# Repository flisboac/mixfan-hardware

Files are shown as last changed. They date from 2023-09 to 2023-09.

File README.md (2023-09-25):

# mixfan-hardware

Hardware for the Mixfan, an USB-connected and powered 12V fan controller, that uses as much stock/cheap parts as possible. 

> TODO: PCB layout

Schematics: [docs/production/usb-fan-controller.pdf](docs/production/usb-fan-controller.pdf)

Schematics

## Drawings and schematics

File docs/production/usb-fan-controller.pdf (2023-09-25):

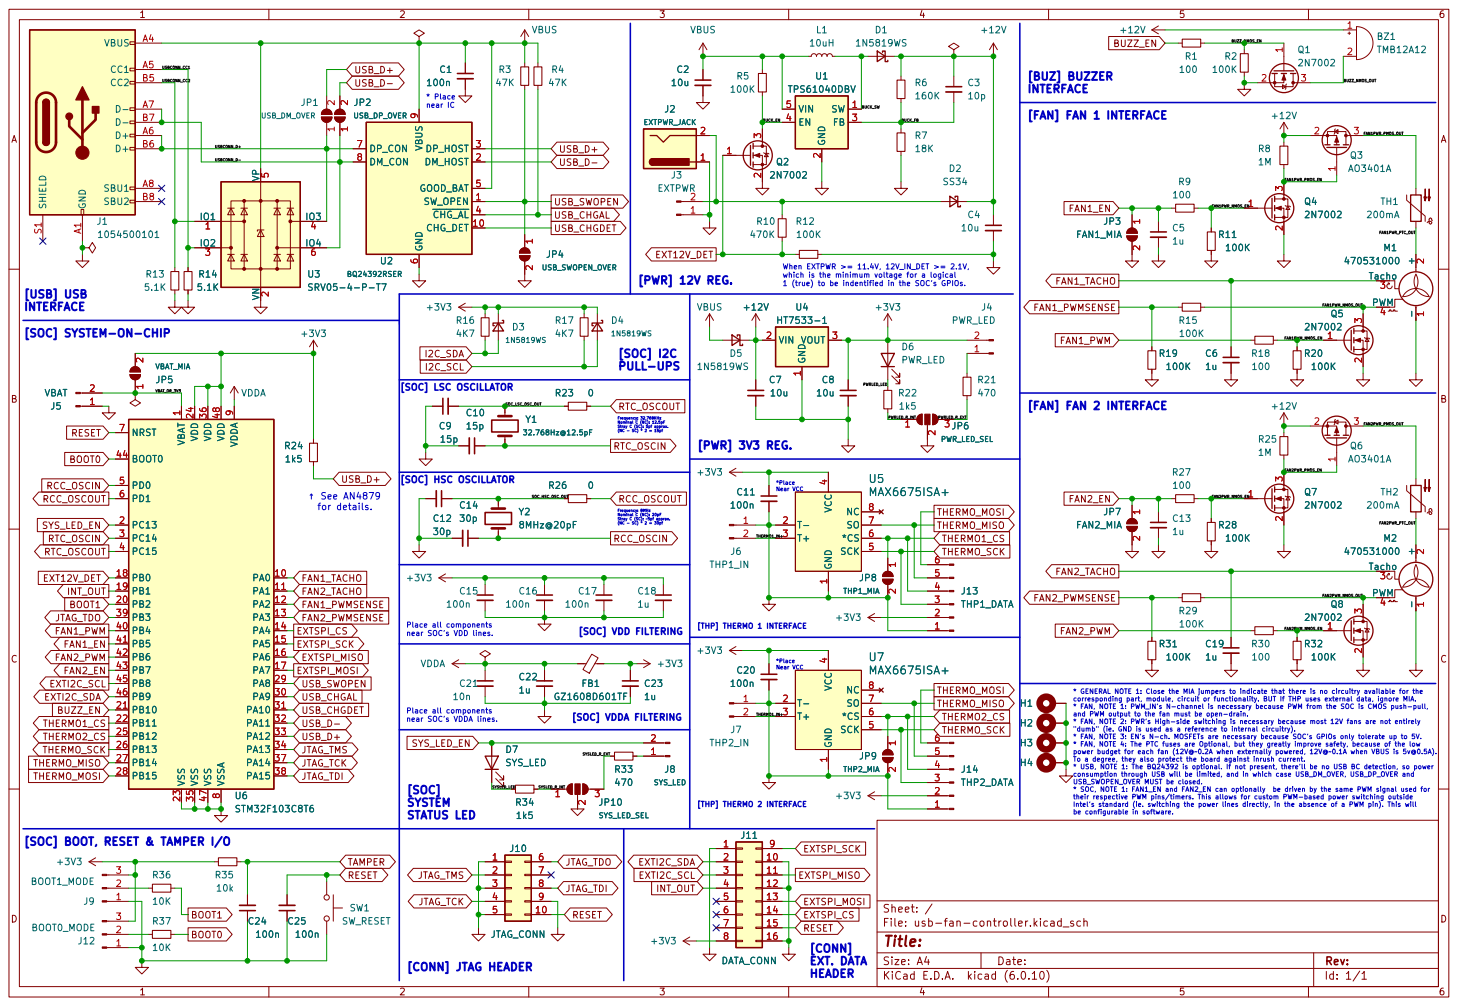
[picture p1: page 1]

When EXTPWR >= 11.4V, 12V_IN_DET >= 2.1V, which is the minimum voltage for a logical 1 (true) to be indentified in the SOC's GPIOs. [PWR] 3V3 REG.

[SOC] SYSTEM-ON-CHIP

1 PA0 10 PA1 11 PA2 12 PA3 13 PA4 14 PA5 15 PA6 16 PA7 17 PB0 18 PB1 19 PC13 2 PB2 20 PB10 21 PB11 22 VSS 23 VDD 24 PB12 25 PB13 26 PB14 27 PB15 28 PA8 29 PC14 3 PA9 30 PA10 31 PA11 32 PA12 33 PA13 34 VSS 35 VDD 36 PA14 37 PA15 38 PB3 39 PC15 4 PB4 40 PB5 41 PB6 42 PB7 43 BOOT0 44 PB8 45 PB9 46 VSS 47 VDD 48 PD0 5 PD1 6 NRST 7 VSSA

Frequency: 32,768KHz Nominal C (NC): 12.5pF Stray C (SC): 5pf approx. (NC - SC) * 2 = 15pf

Frequency: 8MHz Nominal C (NC): 20pF Stray C (SC): ~5pf approx. (NC - SC) * 2 = 30pf Place all components near SOC's VDDA lines.

* GENERAL NOTE 1: Close the MIA jumpers to indicate that there is no circuitry available for the
corresponding part, module, circuit or functionality. BUT If THP uses external data, ignore MIA. * FAN, NOTE 1: PWM_IN's N-channel is necessary because PWM from the SOC is CMOS push-pull, and PWM output to the fan must be open-drain. * FAN, NOTE 2: PWR's High-side switching is necessary because most 12V fans are not entirely

"dumb" (ie. GND is used as a reference to internal circuitry). * FAN, NOTE 3: EN's N-ch. MOSFETs are necessary because SOC's GPIOs only tolerate up to 5V. * FAN, NOTE 4: The PTC fuses are Optional, but they greatly improve safety, because of the low

power budget for each fan (12V@~0.2A when externally powered, 12V@~0.1A when VBUS is 5v@0.5A). To a degree, they also protect the board against inrush current. * USB, NOTE 1: The BQ24392 is optional. If not present, there'll be no USB BC detection, so power consumption through USB will be limited, and in which case USB_DM_OVER, USB_DP_OVER and USB_SWOPEN_OVER MUST be closed. * SOC, NOTE 1: FAN1_EN and FAN2_EN can optionally be driven by the same PWM signal used for

their respective PWM pins/timers. This allows for custom PWM-based power switching outside
Intel's standard (ie. switching the power lines directly, in the absence of a PWM pin). This will be configurable in software.

[SOC] BOOT, RESET & TAMPER I/O

File: usb-fan-controller.kicad_sch Sheet: / R35

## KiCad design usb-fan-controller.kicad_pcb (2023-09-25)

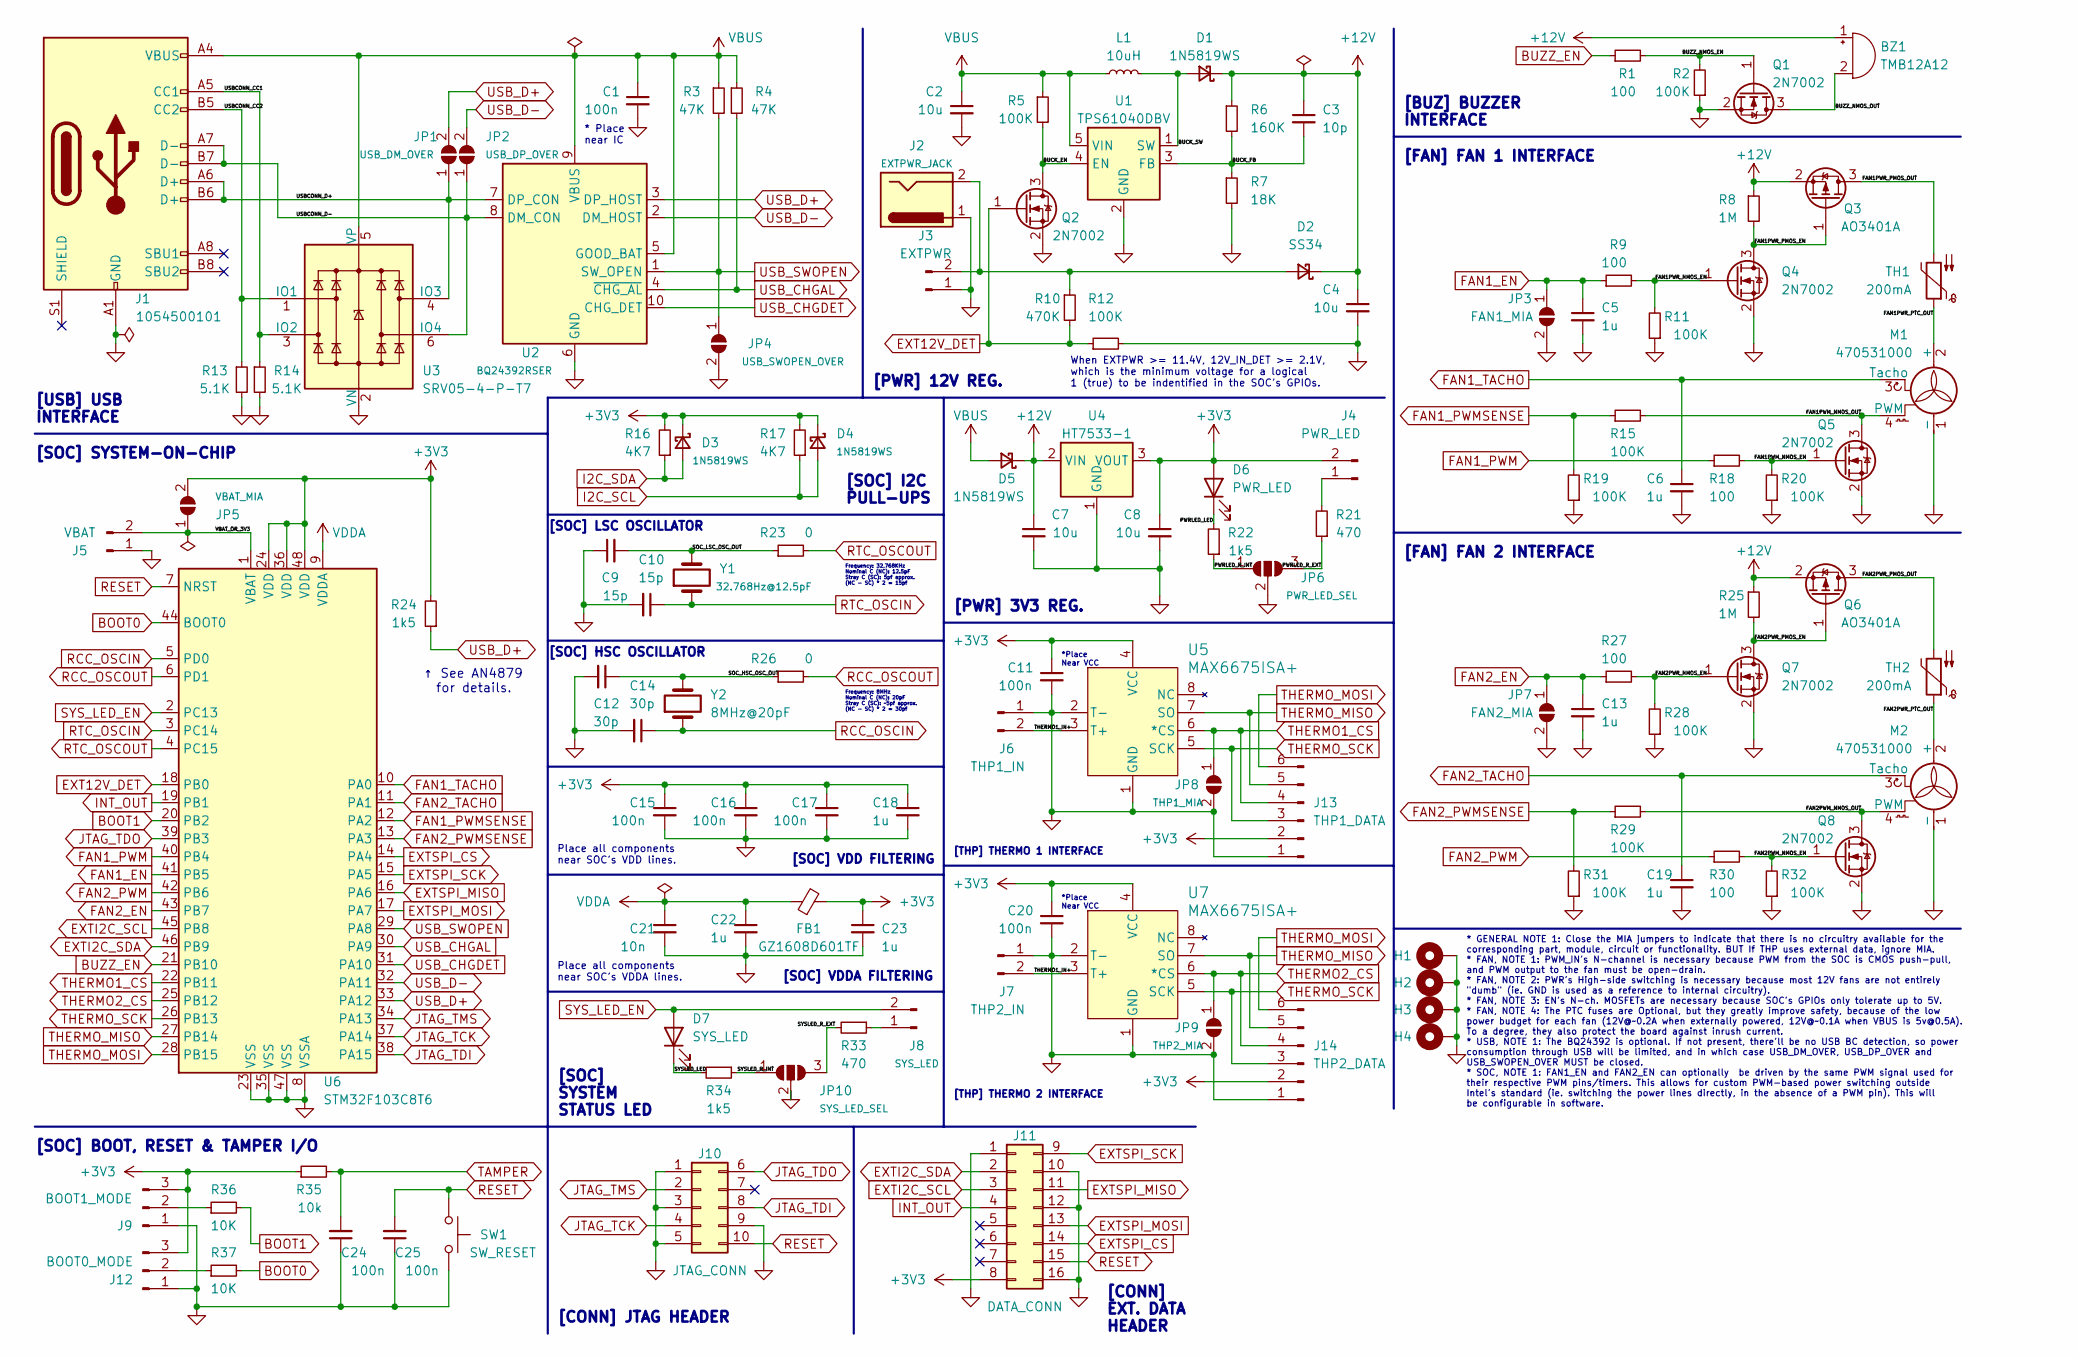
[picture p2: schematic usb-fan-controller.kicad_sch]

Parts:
BZ1: TMB12A12; Buzzer_12x9.5RM7.6; JLCPCB Part C96079
C1, C11, C15, C16, C17, C20, C24, C25: 100n; C_0402_1005Metric_Pad0.74x0.62mm_HandSolder
C2, C4, C7, C8: 10u; C_0603_1608Metric; JLCPCB Part C96446
C3: 10p; C_0402_1005Metric; JLCPCB Part C32949
C5, C6, C13, C18, C19, C22, C23: 1u; C_0402_1005Metric; JLCPCB Part C52923
C9, C10: 15p; C_0402_1005Metric_Pad0.74x0.62mm_HandSolder; JLCPCB Part C32949
C12, C14: 30p; C_0603_1608Metric; JLCPCB Part C1658
C21: 10n; C_0402_1005Metric_Pad0.74x0.62mm_HandSolder; JLCPCB Part C15195
D1, D3, D4, D5: 1N5819WS; D_SOD-323
D2: SS34; D_SMA; JLCPCB Part C8678
D6: PWR_LED; D_0603_1608Metric; JLCPCB Part C2286
D7: SYS_LED; D_0603_1608Metric; JLCPCB Part C2286
FB1: GZ1608D601TF; L_0603_1608Metric
H1, H2, H3, H4: MountingHole_Pad; MountingHole_2.2mm_M2_Pad_Via
J1: 1054500101; USB_C_Receptacle_Molex_105450-0101; JLCPCB Part C134092
J2: EXTPWR_JACK; BarrelJack_CLIFF_FC681465S_SMT_Horizontal
J3: EXTPWR; TerminalBlock_bornier-2_P5.08mm; JLCPCB Part C8465
J4: PWR_LED; LED_D3.0mm; JLCPCB Part C8465
J5: VBAT; JST_PH_B2B-PH-K_1x02_P2.00mm_Vertical; JLCPCB Part C8465
J6: THP1_IN; TerminalBlock_bornier-2_P5.08mm; JLCPCB Part C8465
J7: THP2_IN; TerminalBlock_bornier-2_P5.08mm; JLCPCB Part C8465
J8: SYS_LED; LED_D3.0mm; JLCPCB Part C8465
J9: BOOT1_MODE; PinHeader_1x03_P2.54mm_Vertical
J10: JTAG_CONN; PinHeader_2x05_P2.54mm_Horizontal
J11: DATA_CONN; PinHeader_2x08_P2.54mm_Vertical
J12: BOOT0_MODE; PinHeader_1x03_P2.54mm_Vertical
J13: THP1_DATA
J14: THP2_DATA; PinHeader_1x06_P2.54mm_Horizontal
JP1: USB_DM_OVER; SolderJumper-2_P1.3mm_Open_RoundedPad1.0x1.5mm
JP2: USB_DP_OVER; SolderJumper-2_P1.3mm_Open_RoundedPad1.0x1.5mm
JP3: FAN1_MIA; SolderJumper-2_P1.3mm_Open_RoundedPad1.0x1.5mm
JP4: USB_SWOPEN_OVER; SolderJumper-2_P1.3mm_Open_RoundedPad1.0x1.5mm
JP5: VBAT_MIA; SolderJumper-2_P1.3mm_Open_RoundedPad1.0x1.5mm
JP6: PWR_LED_SEL; SolderJumper-3_P1.3mm_Open_RoundedPad1.0x1.5mm
JP7: FAN2_MIA; SolderJumper-2_P1.3mm_Open_RoundedPad1.0x1.5mm
JP8: THP1_MIA; SolderJumper-2_P1.3mm_Open_RoundedPad1.0x1.5mm
JP9: THP2_MIA; SolderJumper-2_P1.3mm_Open_RoundedPad1.0x1.5mm
JP10: SYS_LED_SEL; SolderJumper-3_P1.3mm_Open_RoundedPad1.0x1.5mm
L1: 10uH; L_0805_2012Metric_Pad1.15x1.40mm_HandSolder; LCSC Part C426327
M1, M2: 470531000; FanPinHeader_1x04_P2.54mm_Vertical
Q1, Q2, Q4, Q5, Q7, Q8: 2N7002; SOT-23
Q3, Q6: AO3401A; SOT-23
R1, R9, R18, R27, R30: 100; R_0402_1005Metric_Pad0.72x0.64mm_HandSolder
R2, R5, R11, R12, R15, R19, R20, R28, R29, R31, R32: 100K; R_0402_1005Metric_Pad0.72x0.64mm_HandSolder
R3, R4: 47K; R_0402_1005Metric_Pad0.72x0.64mm_HandSolder
R6: 160K; R_0603_1608Metric; JLCPCB Part C1035
R7: 18K; R_0603_1608Metric; JLCPCB Part C25810
R8, R25: 1M; R_0402_1005Metric_Pad0.72x0.64mm_HandSolder
R10: 470K; R_0603_1608Metric; JLCPCB Part C23178
R13, R14: 5.1K; R_0402_1005Metric_Pad0.72x0.64mm_HandSolder
R16, R17: 4K7; R_0402_1005Metric_Pad0.72x0.64mm_HandSolder
R21, R33: 470; R_0402_1005Metric_Pad0.72x0.64mm_HandSolder
R22, R24, R34: 1k5; R_0402_1005Metric_Pad0.72x0.64mm_HandSolder
R23, R26: 0; R_0402_1005Metric_Pad0.72x0.64mm_HandSolder
R35: 10k; R_0402_1005Metric_Pad0.72x0.64mm_HandSolder
R36, R37: 10K; R_0402_1005Metric_Pad0.72x0.64mm_HandSolder
SW1: SW_RESET; SW_SPST_SKQG_WithStem; JLCPCB Part C318884
TH1, TH2: 200mA; R_0603_1608Metric; JLCPCB Part C883092
U1: TPS61040DBV; SOT-23-5; JLCPCB Part C7722
U2: BQ24392RSER; Texas_R-PUQFN-N10
U3: SRV05-4-P-T7; SOT-23-6; JLCPCB Part C85364
U4: HT7533-1; SOT-89-3; JLCPCB Part C14289
U5, U7: MAX6675ISA+; MAX6675ISA
U6: STM32F103C8T6; LQFP-48_7x7mm_P0.5mm; JLCPCB Part C8734
Y1: 32.768Hz@12.5pF; Crystal_SMD_3215-2Pin_3.2x1.5mm; JLCPCB Part C32346
Y2: 8MHz@20pF; Crystal_SMD_5032-2Pin_5.0x3.2mm; JLCPCB Part C115962

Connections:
+3V3: C8.1, C11.1, C15.1, C16.1, C17.1, C18.1, C20.1, C23.1, D3.1 (K), D4.1 (K), D6.2 (A), FB1.2, J4.2, J9.3, J11.8, J12.3, J13.2, J14.2, JP5.2 (B), R16.2, R17.2, R24.2, R35.1, U4.3 (VOUT), U5.4 (VCC), U6.24 (VDD), U6.36 (VDD), U6.48 (VDD), U7.4 (VCC)
+12V: BZ1.1 (-), C3.1, C4.1, C7.1, D1.1 (K), D2.1 (K), D5.1 (K), Q3.2 (S), Q6.2 (S), R6.1, R8.1, R25.1, U4.2 (VIN)
/BUCK_EN: Q2.3 (D), R5.2, U1.4 (EN)
/BUCK_FB: C3.2, R6.2, R7.1, U1.3 (FB)
/BUCK_SW: D1.2 (A), L1.2, U1.1 (SW)
/BUZZ_NMOS_EN: Q1.1 (G), R1.2, R2.2
/BUZZ_NMOS_OUT: BZ1.2 (+), Q1.3 (D)
/FAN1PWM_NMOS_EN: Q5.1 (G), R18.2, R20.2
/FAN1PWM_NMOS_OUT: M1.4 (PWM), Q5.3 (D), R15.2
/FAN1PWR_NMOS_EN: Q4.1 (G), R9.2, R11.2
/FAN1PWR_PMOS_EN: Q3.1 (G), Q4.3 (D), R8.2
/FAN1PWR_PMOS_OUT: Q3.3 (D), TH1.2
/FAN1PWR_PTC_OUT: M1.2 (+), TH1.1
/FAN2PWM_NMOS_EN: Q8.1 (G), R30.2, R32.2
/FAN2PWM_NMOS_OUT: M2.4 (PWM), Q8.3 (D), R29.2
/FAN2PWR_NMOS_EN: Q7.1 (G), R27.2, R28.2
/FAN2PWR_PMOS_EN: Q6.1 (G), Q7.3 (D), R25.2
/FAN2PWR_PMOS_OUT: Q6.3 (D), TH2.2
/FAN2PWR_PTC_OUT: M2.2 (+), TH2.1
/PWRLED_LED: D6.1 (K), R22.2
/PWRLED_R_EXT: JP6.3 (B), R21.1
/PWRLED_R_INT: JP6.1 (A), R22.1
/SOC_HSC_OSC_OUT: C12.1, R26.1, Y2.2
/SOC_LSC_OSC_OUT: C9.2, R23.1, Y1.2
/SYSLED_LED: D7.1 (K), R34.2
/SYSLED_R_EXT: JP10.3 (B), R33.2
/SYSLED_R_INT: JP10.1 (A), R34.1
/THERMO1_IN+: J6.2, J7.2, U5.3 (T+), U7.3 (T+)
/USBCONN_CC1: J1.A5 (CC1), R14.1, U3.3 (IO2)
/USBCONN_CC2: J1.B5 (CC2), R13.1, U3.1 (IO1)
/USBCONN_D+: J1.A6 (D+), J1.B6 (D+), JP1.1 (A), U2.7 (DP_CON), U3.4 (IO3)
/USBCONN_D-: J1.A7 (D-), J1.B7 (D-), JP2.1 (A), U2.8 (DM_CON), U3.6 (IO4)
/VBAT_OR_3V3: J5.2, JP5.1 (A), U6.1 (VBAT)
BOOT0: R37.2, U6.44 (BOOT0)
BOOT1: R36.2, U6.20 (PB2)
BUZZ_EN: R1.1, U6.21 (PB10)
EXT12V_DET: Q2.1 (G), R10.2, R12.1, U6.18 (PB0)
EXTI2C_SCL: J11.3, U6.45 (PB8)
EXTI2C_SDA: J11.2, U6.46 (PB9)
EXTSPI_CS: J11.14, U6.14 (PA4)
EXTSPI_MISO: J11.11, U6.16 (PA6)
EXTSPI_MOSI: J11.13, U6.17 (PA7)
EXTSPI_SCK: J11.9, U6.15 (PA5)
FAN1_EN: C5.1, JP3.1 (A), R9.1, U6.41 (PB5)
FAN1_PWM: R18.1, U6.40 (PB4)
FAN1_PWMSENSE: R15.1, R19.2, U6.12 (PA2)
FAN1_TACHO: C6.1, M1.3 (Tacho), U6.10 (PA0)
FAN2_EN: C13.1, JP7.1 (A), R27.1, U6.43 (PB7)
FAN2_PWM: R30.1, U6.42 (PB6)
FAN2_PWMSENSE: R29.1, R31.2, U6.13 (PA3)
FAN2_TACHO: C19.1, M2.3 (Tacho), U6.11 (PA1)
GND: C1.2, C2.2, C4.2, C5.2, C6.2, C7.2, C8.2, C9.1, C10.2, C11.2, C12.2, C13.2, C14.2, C15.2, C16.2, C17.2, C18.2, C19.2, C20.2, C21.2, C22.2, C23.2, C24.1, C25.1, H1.1, H2.1, H3.1, H4.1, J1.A1 (GND), J1.A12 (GND), J1.B1 (GND), J1.B12 (GND), J2.1, J3.1, J5.1, J6.1, J7.1, J9.1, J10.1, J10.3, J10.5, J10.9, J11.1, J11.10, J11.12, J11.16, J12.1, J13.1, J14.1, JP3.2 (B), JP4.2 (B), JP6.2 (C), JP7.2 (B), JP8.2 (B), JP9.2 (B), JP10.2 (C), M1.1 (-), M2.1 (-), Q1.2 (S), Q2.2 (S), Q4.2 (S), Q5.2 (S), Q7.2 (S), Q8.2 (S), R2.1, R7.2, R11.1, R12.2, R13.2, R14.2, R19.1, R20.1, R28.1, R31.1, R32.1, SW1.1, U1.2 (GND), U2.6 (GND), U3.2 (VN), U4.1 (GND), U5.1 (GND), U5.2 (T-), U6.8 (VSSA), U6.23 (VSS), U6.35 (VSS), U6.47 (VSS), U7.1 (GND), U7.2 (T-)
I2C_SCL: D4.2 (A), R17.1
I2C_SDA: D3.2 (A), R16.1
INT_OUT: J11.4, U6.19 (PB1)
JTAG_TCK: J10.4, U6.37 (PA14)
JTAG_TDI: J10.8, U6.38 (PA15)
JTAG_TDO: J10.6, U6.39 (PB3)
JTAG_TMS: J10.2, U6.34 (PA13)
unnamed: D2.2 (A), J2.2, J3.2, R10.1
unnamed: J4.1, R21.2
unnamed: J8.1, R33.1
unnamed: J9.2, R36.1
unnamed: J12.2, R37.1
RCC_OSCIN: C14.1, U6.5 (PD0), Y2.1
RCC_OSCOUT: R26.2, U6.6 (PD1)
RESET: C25.2, J10.10, J11.15, SW1.2, U6.7 (NRST)
RTC_OSCIN: C10.1, U6.3 (PC14), Y1.1
RTC_OSCOUT: R23.2, U6.4 (PC15)
SYS_LED_EN: D7.2 (A), J8.2, U6.2 (PC13)
TAMPER: C24.2, R35.2
THERMO1_CS: J13.4, JP8.1 (A), U5.6 (*CS), U6.22 (PB11)
THERMO2_CS: J14.4, JP9.1 (A), U6.25 (PB12), U7.6 (*CS)
THERMO_MISO: J13.5, J14.5, U5.7 (SO), U6.27 (PB14), U7.7 (SO)
THERMO_MOSI: J13.6, J14.6, U6.28 (PB15)
THERMO_SCK: J13.3, J14.3, U5.5 (SCK), U6.26 (PB13), U7.5 (SCK)
USB_CHGAL: R4.2, U2.4 (~CHG_AL), U6.30 (PA9)
USB_CHGDET: U2.10 (CHG_DET), U6.31 (PA10)
USB_D+: JP1.2 (B), R24.1, U2.3 (DP_HOST), U6.33 (PA12)
USB_D-: JP2.2 (B), U2.2 (DM_HOST), U6.32 (PA11)
USB_SWOPEN: JP4.1 (A), R3.2, U2.1 (SW_OPEN), U6.29 (PA8)
VBUS: C1.1, C2.1, D5.2 (A), J1.A4 (VBUS), J1.A9 (VBUS), J1.B4 (VBUS), J1.B9 (VBUS), L1.1, R3.1, R4.1, R5.1, U1.5 (VIN), U2.5 (GOOD_BAT), U2.9 (VBUS), U3.5 (VP)
VDDA: C21.1, C22.1, FB1.1, U6.9 (VDDA)

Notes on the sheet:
* Place near IC
*Place Near VCC
When EXTPWR >= 11.4V, 12V_IN_DET >= 2.1V, which is the minimum voltage for a logical 1 (true) to be indentified in the SOC's GPIOs.
[USB] USB INTERFACE
[CONN] EXT. DATA HEADER
↑ See AN4879 for details.
Frequency: 32,768KHz Nominal C (NC): 12.5pF Stray C (SC): 5pf approx. (NC - SC) * 2 = 15pf
[PWR] 12V REG.
* GENERAL NOTE 1: Close the MIA jumpers to indicate that there is no circuitry available for the corresponding part, module, circuit or functionality. BUT If THP uses external data, ignore MIA. * FAN, NOTE 1: PWM_IN's N-channel is necessary because PWM from the SOC is CMOS push-pull, and PWM output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
[FAN] FAN 2 INTERFACE
Place all components near SOC's VDD lines.
[FAN] FAN 1 INTERFACE
[SOC] LSC OSCILLATOR
[SOC] SYSTEM STATUS LED
Place all components near SOC's VDDA lines.
[SOC] SYSTEM-ON-CHIP
[THP] THERMO 1 INTERFACE
[SOC] BOOT, RESET & TAMPER I/O
[CONN] JTAG HEADER
[SOC] I2C PULL-UPS
Frequency: 8MHz Nominal C (NC): 20pF Stray C (SC): ~5pf approx. (NC - SC) * 2 = 30pf
[BUZ] BUZZER INTERFACE
[SOC] VDDA FILTERING
[THP] THERMO 2 INTERFACE
[PWR] 3V3 REG.
[SOC] VDD FILTERING
[SOC] HSC OSCILLATOR

Board: 2 copper layers, 122 parts (0 on the bottom side), 83 nets, no tracks yet.

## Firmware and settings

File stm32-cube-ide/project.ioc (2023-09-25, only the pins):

Mcu.UserName=STM32F103C8Tx
PA0-WKUP.GPIO_Label=FAN1_TACHO
PA0-WKUP.Signal=ADCx_IN0
PA1.GPIO_Label=FAN2_TACHO
PA1.Signal=ADCx_IN1
PA10.GPIO_Label=USB_CHGDET
PA10.Signal=GPIO_Input
PA11.Signal=USB_DM
PA12.Signal=USB_DP
PA13.GPIO_Label=JTAG_TMS
PA13.Signal=SYS_JTMS-SWDIO
PA14.GPIO_Label=JTAG_TCK
PA14.Signal=SYS_JTCK-SWCLK
PA15.GPIO_Label=JTAG_TDI
PA15.Signal=SYS_JTDI
PA2.GPIO_Label=FAN1_PWMSENSE
PA2.Signal=ADCx_IN2
PA3.GPIO_Label=FAN2_PWMSENSE
PA3.Signal=ADCx_IN3
PA4.GPIO_Label=EXTSPI_CS
PA4.Signal=SPI1_NSS
PA5.GPIO_Label=EXTSPI_SCK
PA5.Signal=SPI1_SCK
PA6.GPIO_Label=EXTSPI_MISO
PA6.Signal=SPI1_MISO
PA7.GPIO_Label=EXTSPI_MOSI
PA7.Signal=SPI1_MOSI
PA8.GPIO_Label=USB_SWOPEN
PA8.Signal=GPIO_Input
PA9.GPIO_Label=USB_CHGAL
PA9.Signal=GPIO_Input
PB0.GPIO_Label=EXT12V_DET
PB0.Signal=ADCx_IN8
PB1.GPIO_Label=INT_OUT
PB1.Signal=GPIO_Output
PB10.GPIO_Label=BUZZ_EN
PB10.Signal=GPIO_Output
PB11.GPIO_Label=THERMO1_CS
PB11.Signal=GPIO_Output
PB12.GPIO_Label=THERMO2_CS
PB12.Signal=GPIO_Output
PB13.GPIO_Label=THERMO_SCK
PB13.Signal=SPI2_SCK
PB14.GPIO_Label=THERMO_MISO
PB14.Signal=SPI2_MISO
PB15.GPIO_Label=THERMO_MOSI
PB15.Signal=SPI2_MOSI
PB3.GPIO_Label=JTAG_TDO
PB3.Signal=SYS_JTDO-TRACESWO
PB4.GPIO_Label=FAN1_PWM
PB4.Signal=S_TIM3_CH1
PB5.GPIO_Label=FAN1_EN
PB5.Signal=S_TIM3_CH2
PB6.GPIO_Label=FAN2_PWM
PB6.Signal=S_TIM4_CH1
PB7.GPIO_Label=FAN2_EN
PB7.Signal=S_TIM4_CH2
PB8.GPIO_Label=EXTI2C_SCL
PB8.Signal=I2C1_SCL
PB9.GPIO_Label=EXTI2C_SDA
PB9.Signal=I2C1_SDA
PC13-TAMPER-RTC.GPIO_Label=SYS_LED_EN
PC13-TAMPER-RTC.Signal=GPIO_Output
PC14-OSC32_IN.Signal=RCC_OSC32_IN
PC15-OSC32_OUT.Signal=RCC_OSC32_OUT
PD0-OSC_IN.Signal=RCC_OSC_IN
PD1-OSC_OUT.Signal=RCC_OSC_OUT

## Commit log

2023-09-25 feat: initial commit
    [conn_extpwr.kicad_sch, conn_usb.kicad_sch, pwr_buzz_interf.kicad_sch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]
2023-09-25 feat: add stm32-cube-ide project
2023-09-25 feat: add external THM SPI connection
    [usb-fan-controller.kicad_pcb, usb-fan-controller.kicad_sch]
